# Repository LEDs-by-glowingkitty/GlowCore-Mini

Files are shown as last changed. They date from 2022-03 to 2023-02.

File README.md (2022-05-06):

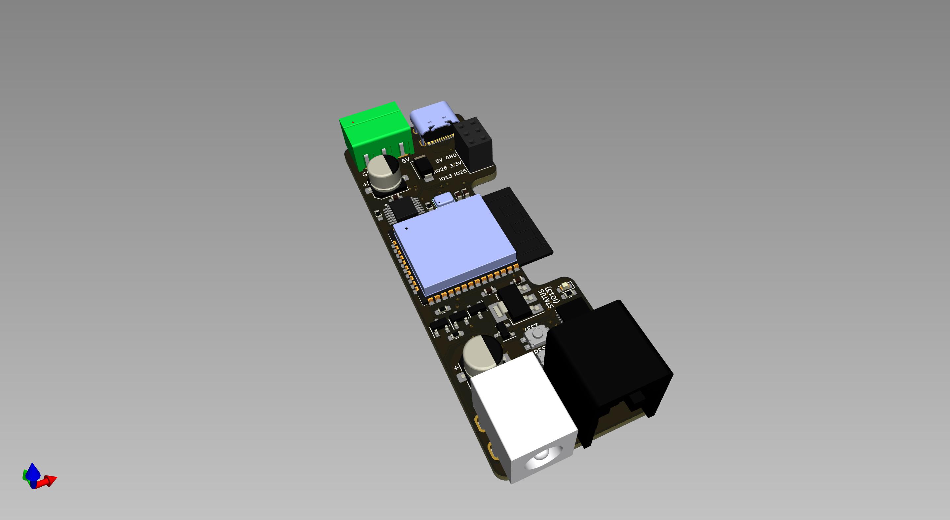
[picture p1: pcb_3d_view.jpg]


# GlowCoreMini

## Warning:

This project is currently under active development and has not been fully tested yet. If you decide to build or clone the project, be aware the project might not work yet as expected. Use at your own risk.

## What is this project?

A small PCB for controlling one LED strip. Program the integrated ESP32, and power everything via USB-C or DC power.

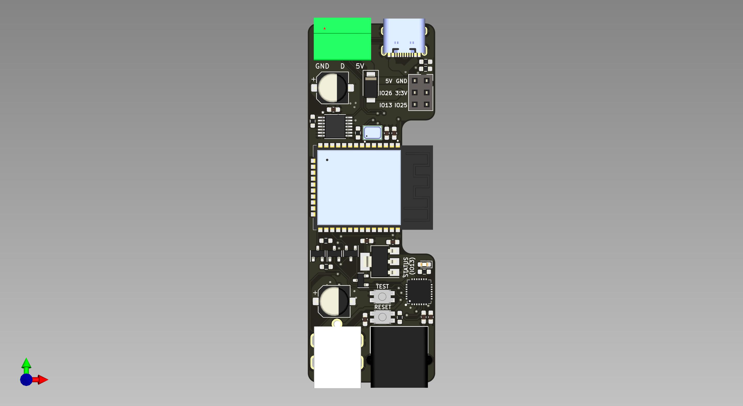
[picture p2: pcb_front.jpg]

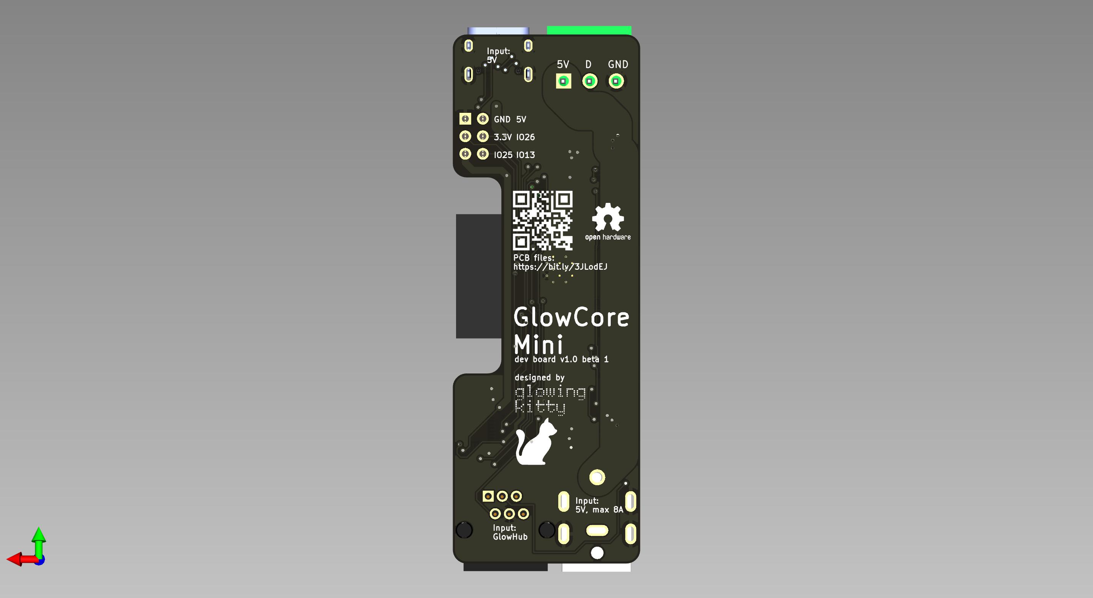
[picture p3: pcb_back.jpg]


## Links

- [Schematic](https://github.com/glowingkitty/GlowCoreMini/blob/main/GlowCoreMini.pdf)
- [Interactive BOM](https://htmlpreview.github.io/?https://github.com/glowingkitty/GlowCoreMini/blob/main/bom/ibom.html)
- [PCB stencils](https://github.com/glowingkitty/GlowCoreMini/blob/main/PCB%20stencils)

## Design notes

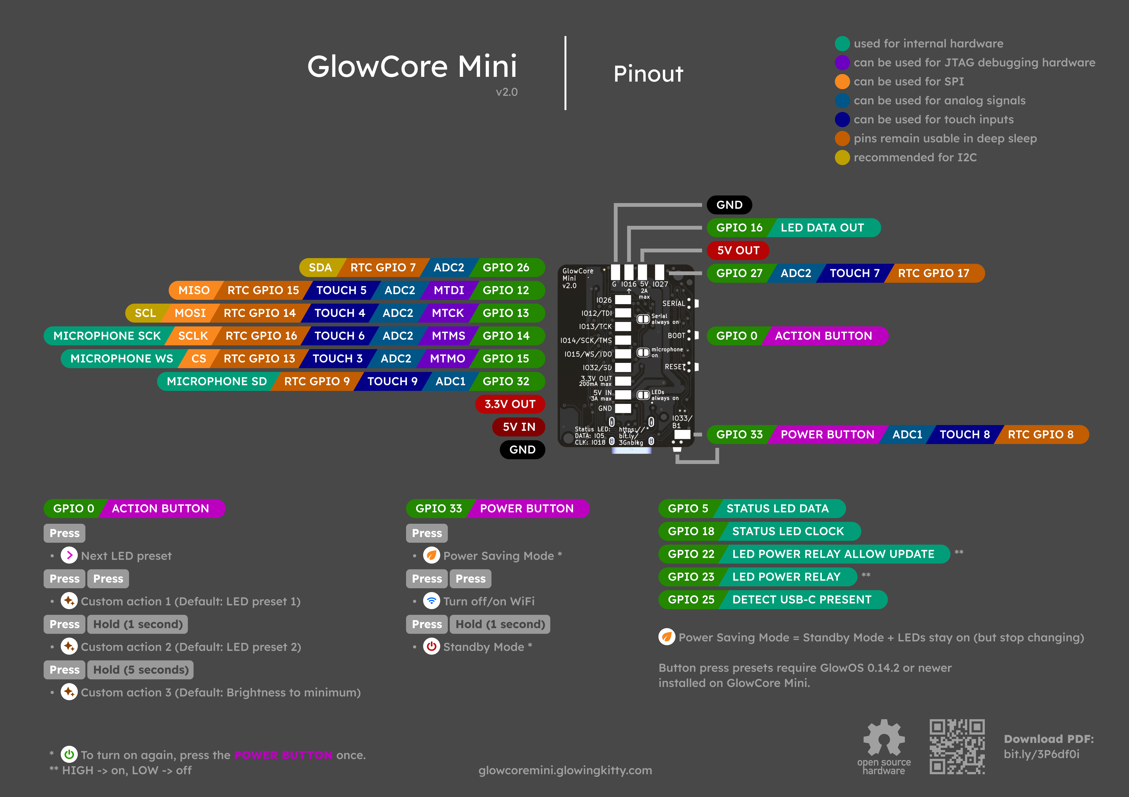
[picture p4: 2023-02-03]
documents/pinout GlowCore Mini v2.0.jpg

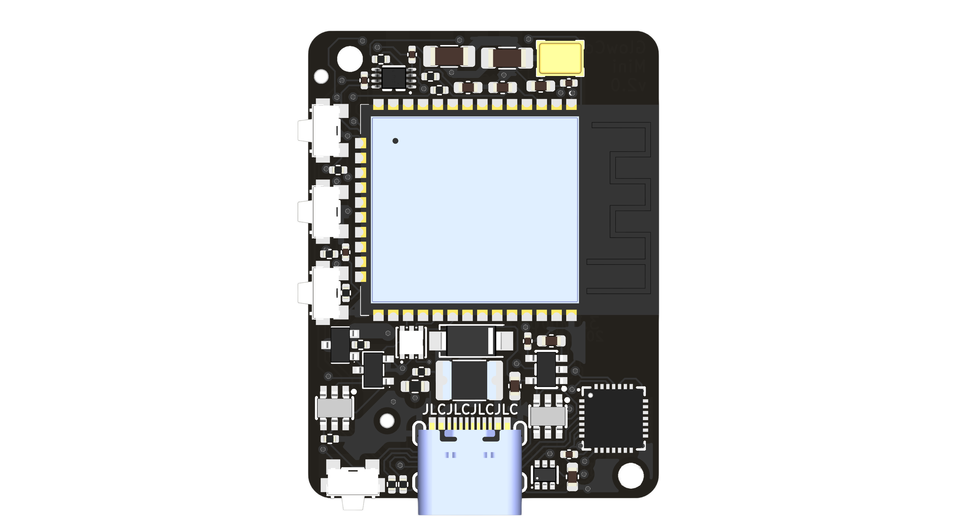
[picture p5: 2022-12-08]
images/GlowCoreMini PCB cutout.png

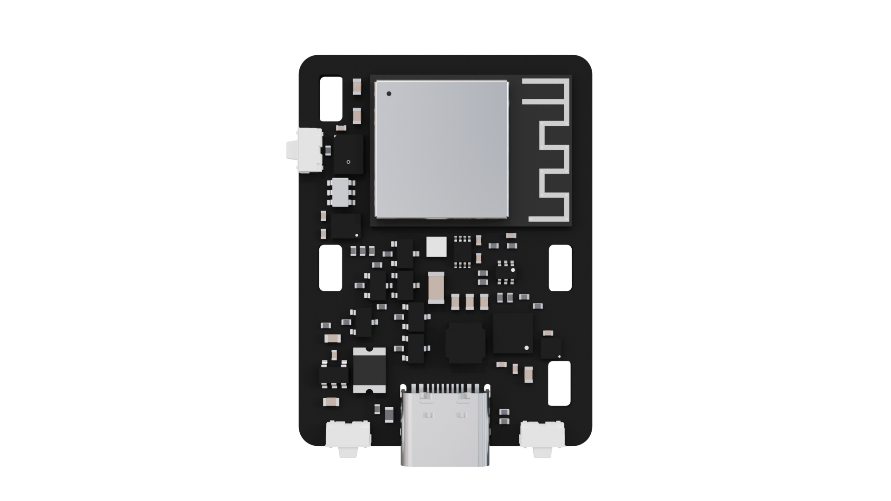
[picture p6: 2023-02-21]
renders/front.png

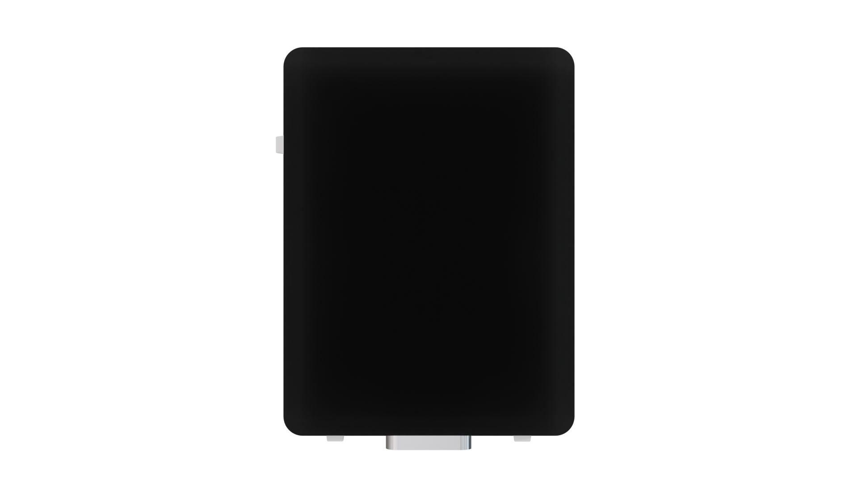
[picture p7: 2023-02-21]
renders/frontwithcase.png

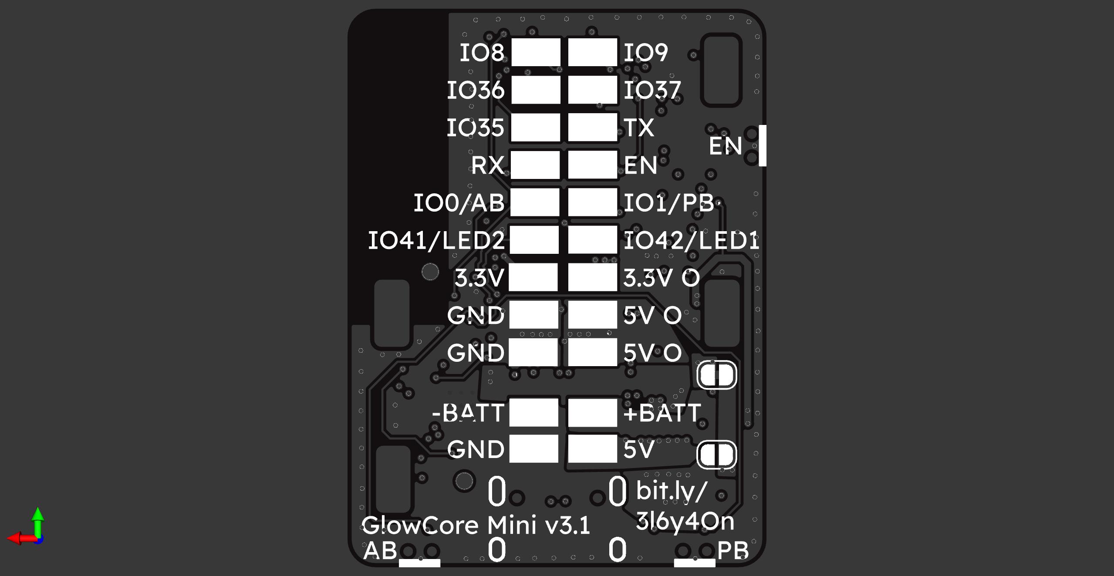
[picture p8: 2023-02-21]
3D files/Blender files/textures/pcb_back.jpg

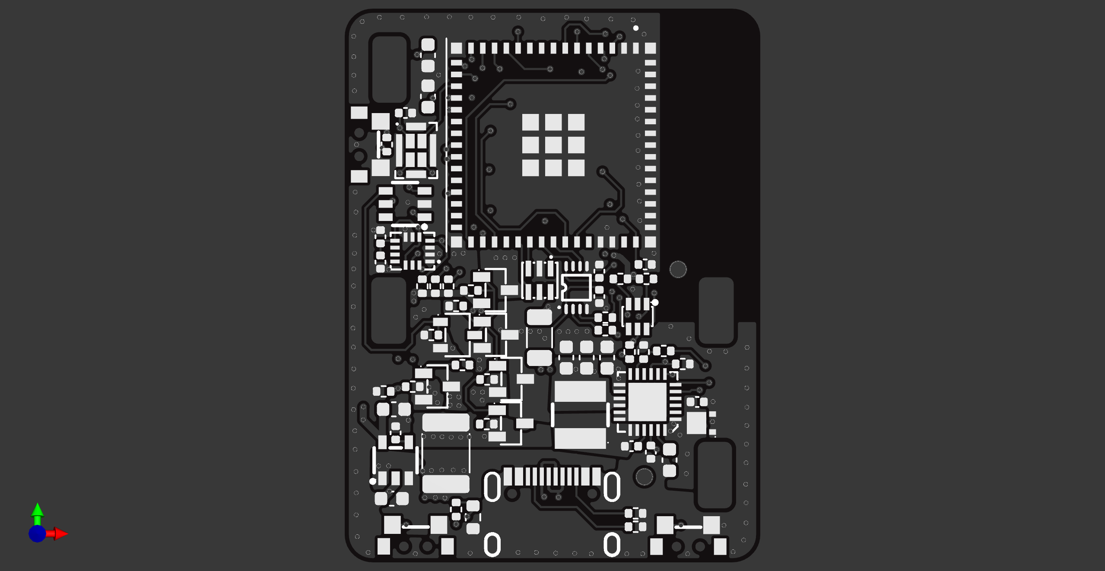
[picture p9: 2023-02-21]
3D files/Blender files/textures/pcb_front.png

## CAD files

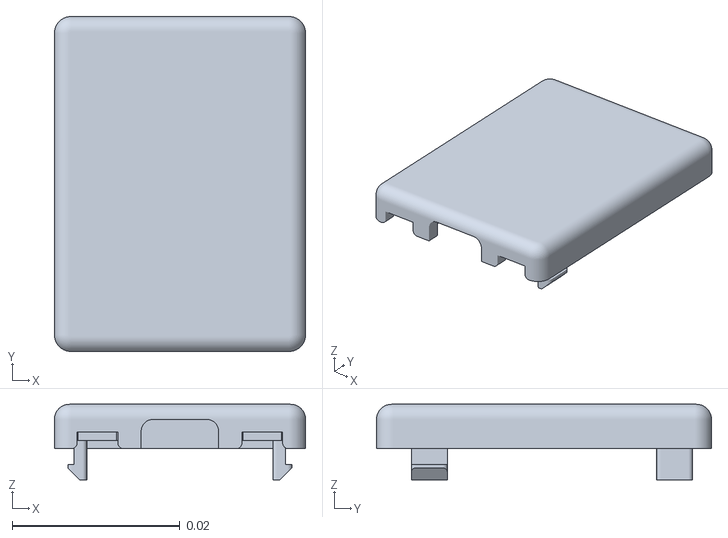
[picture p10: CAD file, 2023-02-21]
3D files/Blender files/case.obj
0.03 x 0.04 x 0.00902

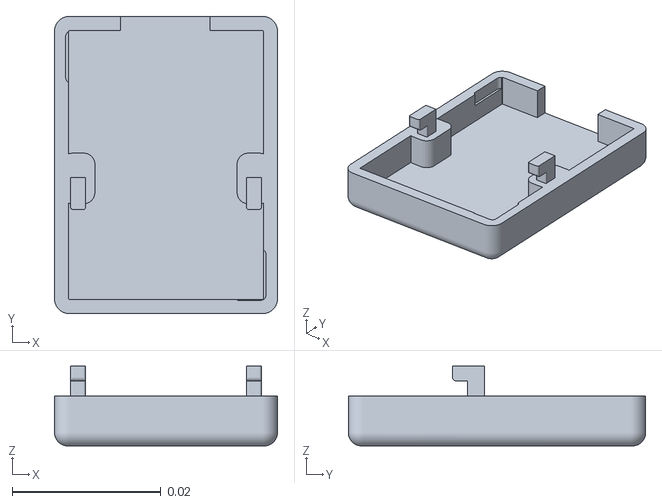
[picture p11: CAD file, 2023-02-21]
3D files/Blender files/back case.obj
0.03 x 0.04 x 0.0108

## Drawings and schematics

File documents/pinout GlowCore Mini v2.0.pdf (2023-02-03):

# GlowCore Mini

# Pinout

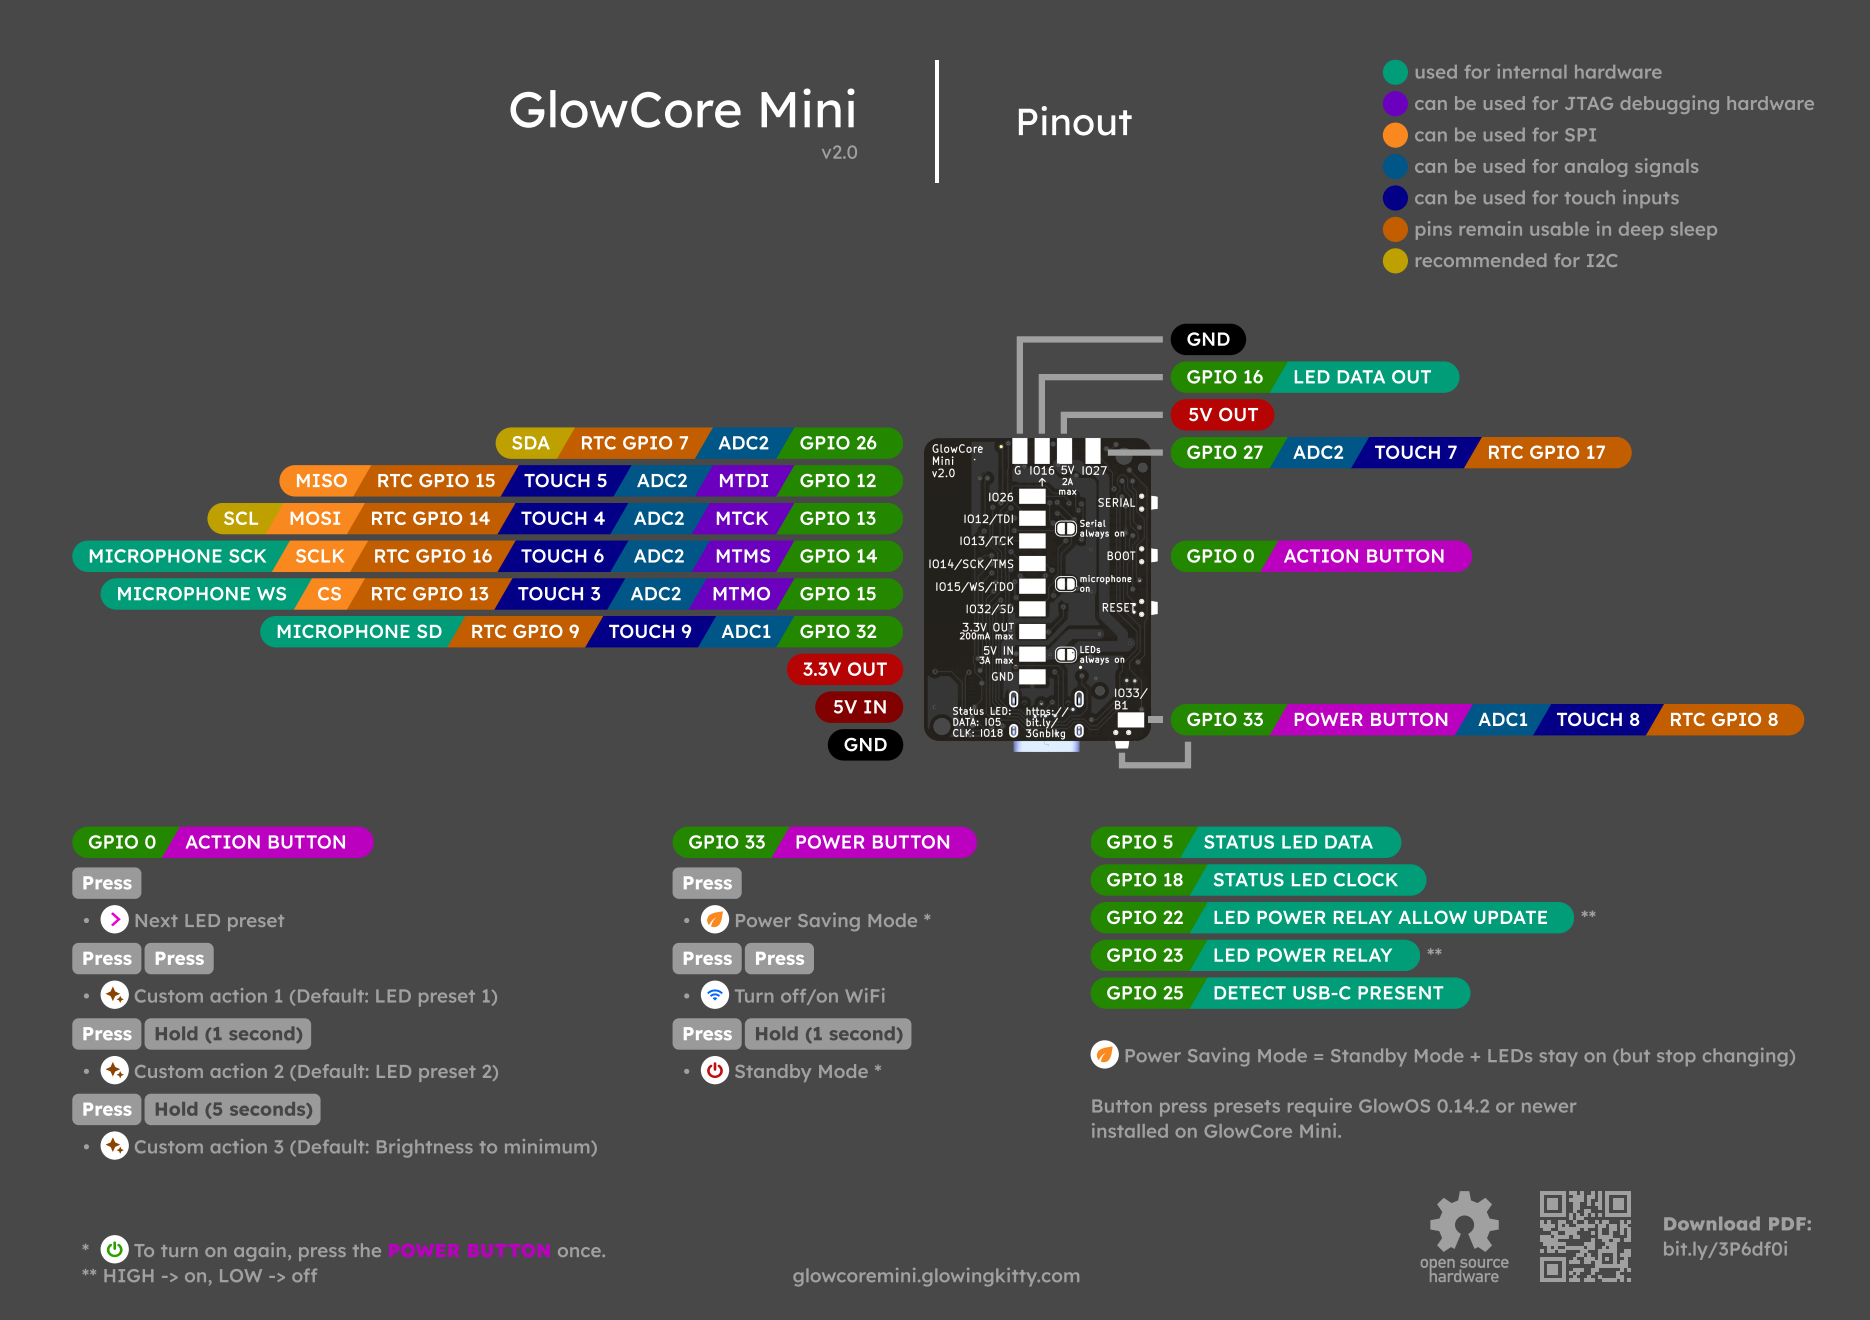
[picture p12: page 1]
recommended for I2C; SDA; RTC GPIO 7; ADC2; GPIO 26; MISO; RTC GPIO 15; TOUCH 5; MTDI; GPIO 12; SCL; MOSI; RTC GPIO 14; TOUCH 4; MTCK; GPIO 13; MICROPHONE SCK; SCLK; RTC GPIO 16; TOUCH 6; MTMS; GPIO 14; MICROPHONE WS; RTC GPIO 13; TOUCH 3; MTMO; GPIO 15; MICROPHONE SD; RTC GPIO 9; TOUCH 9; ADC1; GPIO 32; 3.3V OUT; GND; GPIO 16; LED DATA OUT; 5V OUT; GPIO 27; TOUCH 7; RTC GPIO 17; GPIO 33; POWER BUTTON; TOUCH 8; RTC GPIO 8; GPIO 0; ACTION BUTTON; GPIO 5; STATUS LED DATA; GPIO 18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

used for internal hardware

can be used for JTAG debugging hardware

can be used for SPI

can be used for analog signals

can be used for touch inputs

pins remain usable in deep sleep

Power Saving Mode = Standby Mode + LEDs stay on (but stop changing)

Press & hold 5 sec

Button press presets require GlowOS 0.14.2 or newer

installed on GlowCore Mini.

** HIGH -> on, LOW -> off

glowcoremini.glowingkitty.com

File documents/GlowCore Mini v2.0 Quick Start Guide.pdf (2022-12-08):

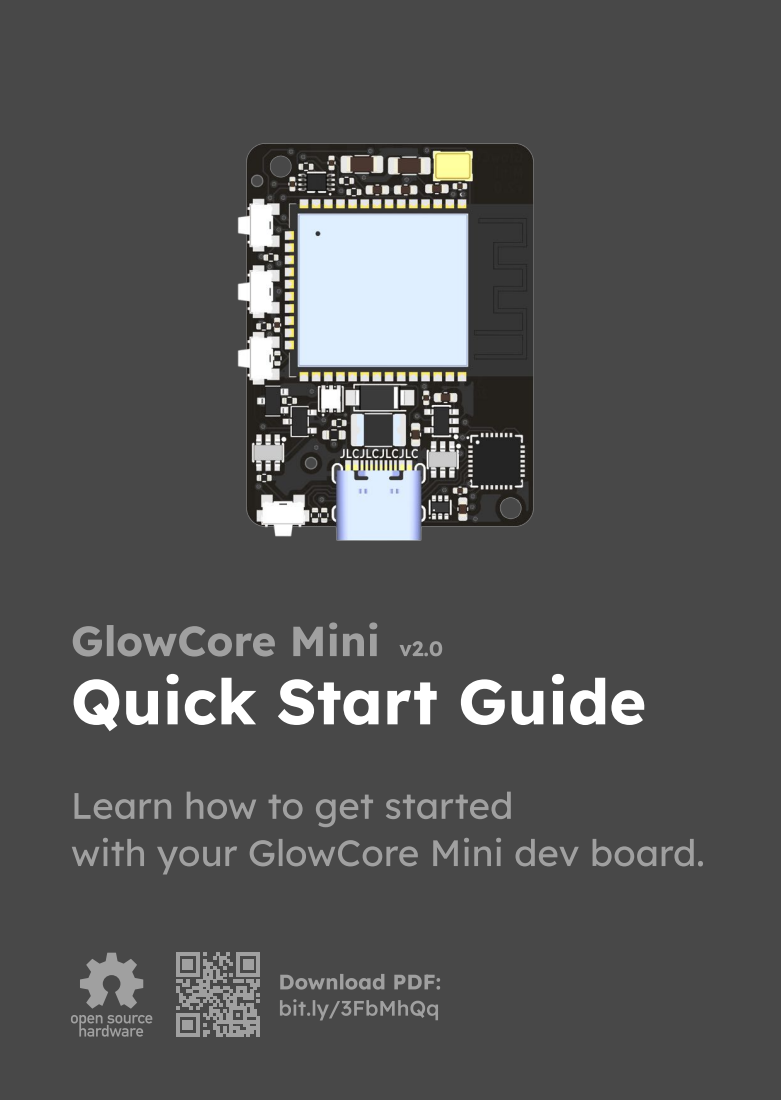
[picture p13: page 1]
Download PDF: bit.ly/3FbMhQq

GlowCore Mini v2.0
Quick Start Guide

Learn how to get started
with your GlowCore Mini dev board.

## bit.ly/3P6df0i

# Step 1:

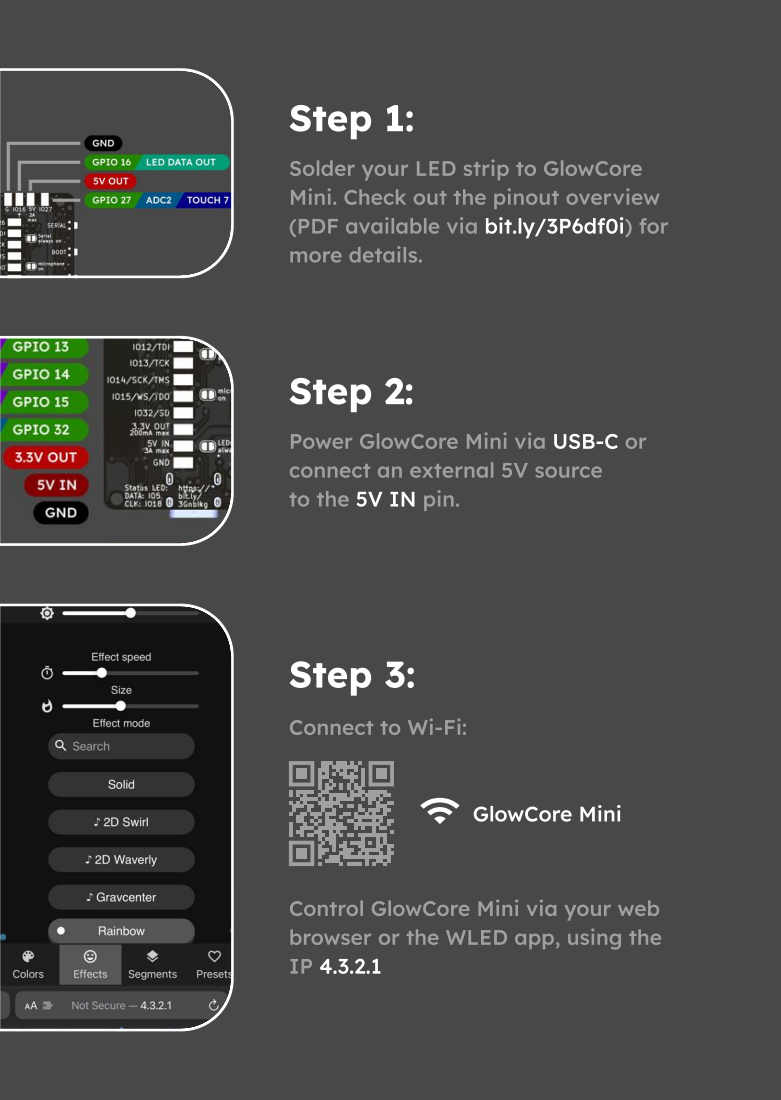
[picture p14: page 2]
(PDF available via; ) for; more details.; GlowCore Mini; Power GlowCore Mini via; to the; pin.; USB-C; Step 2:; Step 3:

Solder your LED strip to GlowCore

Mini. Check out the pinout overview

connect an external 5V source

Connect to Wi-Fi:

Control GlowCore Mini via your web

browser or the WLED app, using the

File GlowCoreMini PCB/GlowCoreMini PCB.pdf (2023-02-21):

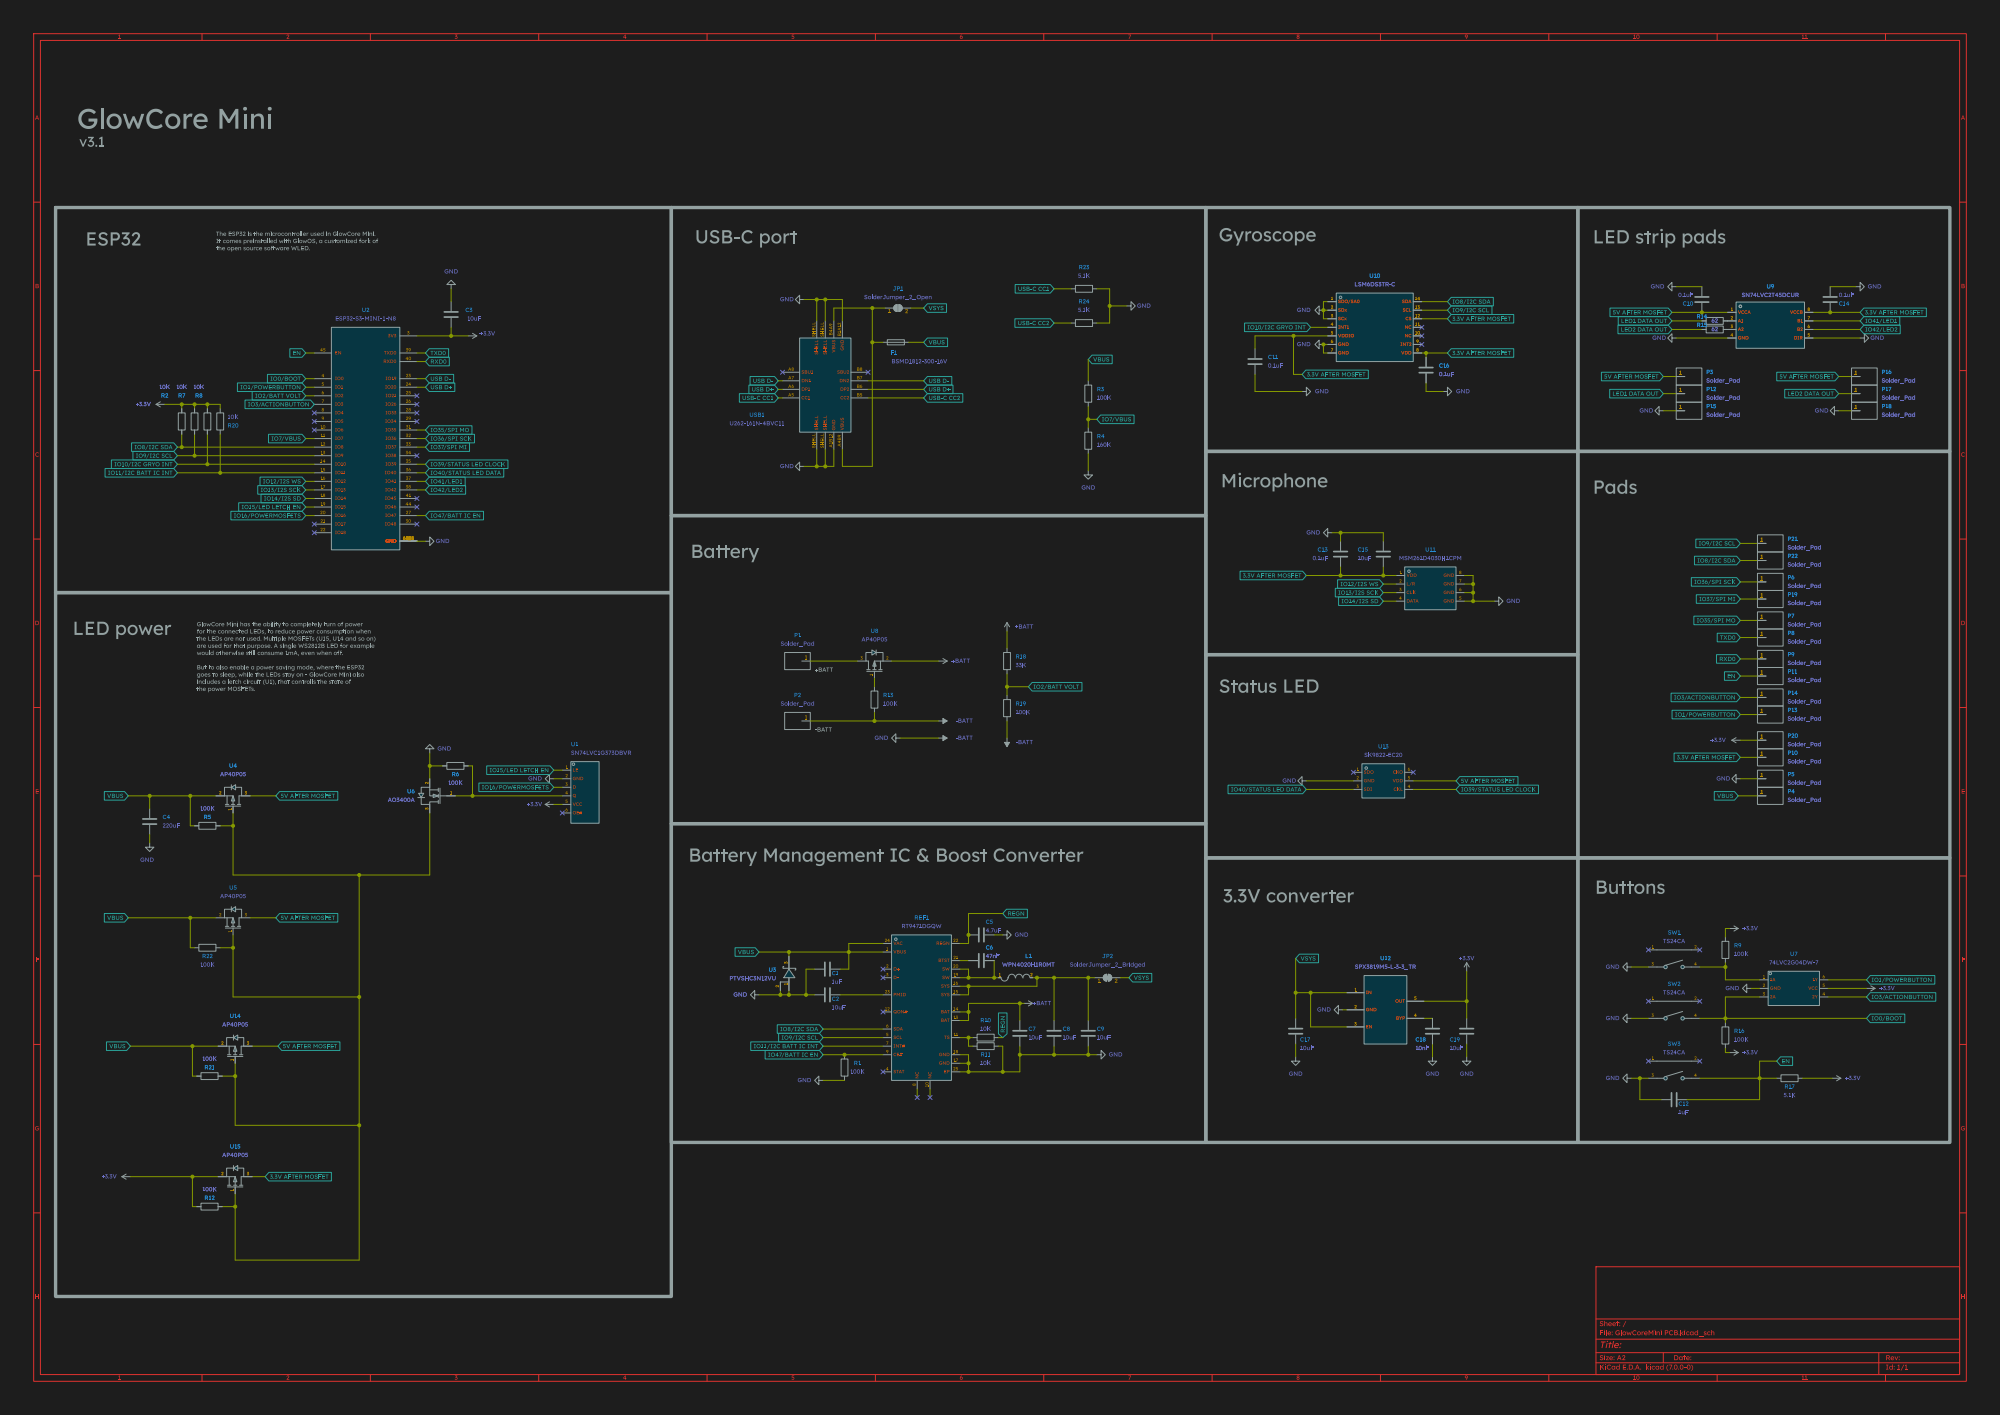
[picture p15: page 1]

It comes preinstalled with GlowOS, a customized fork of

VBUS USB D- USB-C CC1 USB D+ USB D-

IO40/STATUS LED DATA USB D+

the power MOSFETs. LED power

GlowCore Mini has the ability to completely turn of power
for the connected LEDs, to reduce power consumption when
the LEDs are not used. Multiple MOSFETs(U15, U14 and so on) are used for that purpose. A single WS2812B LED for example would otherwise still consume 1mA, even when off. But to also enable a power saving mode, where the ESP32

goes to sleep, while the LEDs stay on - GlowCore Mini also
includes a letch circuit (U1), that controlls the state of

Id: 1/1 Title: File: GlowCoreMini PCB.kicad_sch Sheet: /

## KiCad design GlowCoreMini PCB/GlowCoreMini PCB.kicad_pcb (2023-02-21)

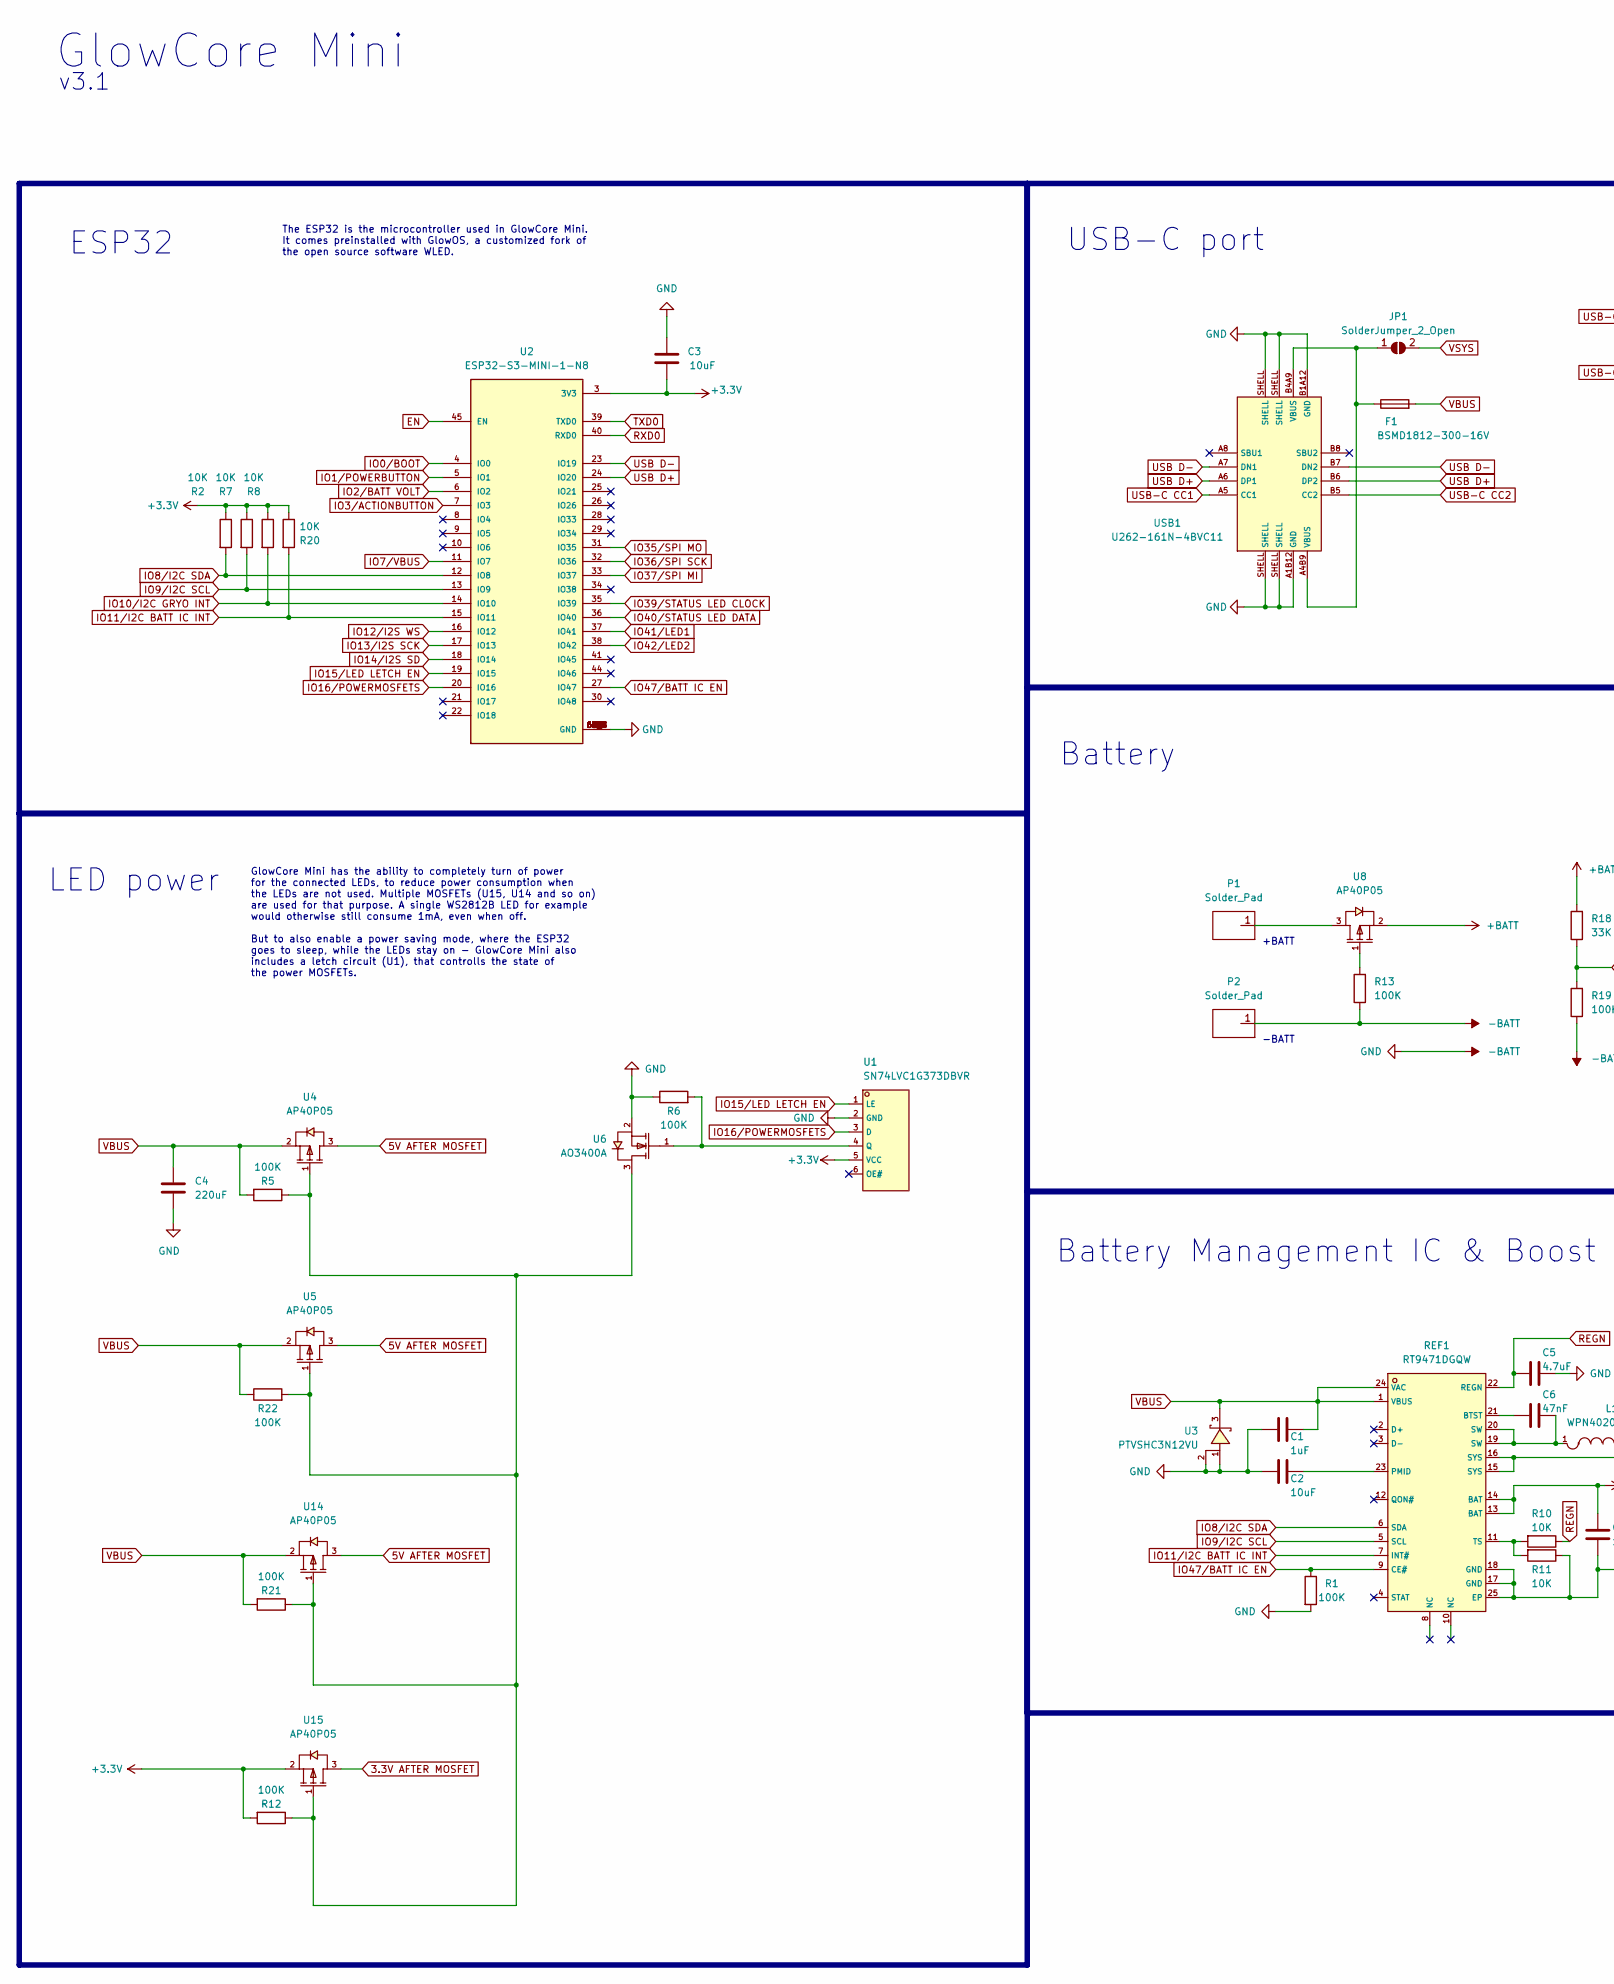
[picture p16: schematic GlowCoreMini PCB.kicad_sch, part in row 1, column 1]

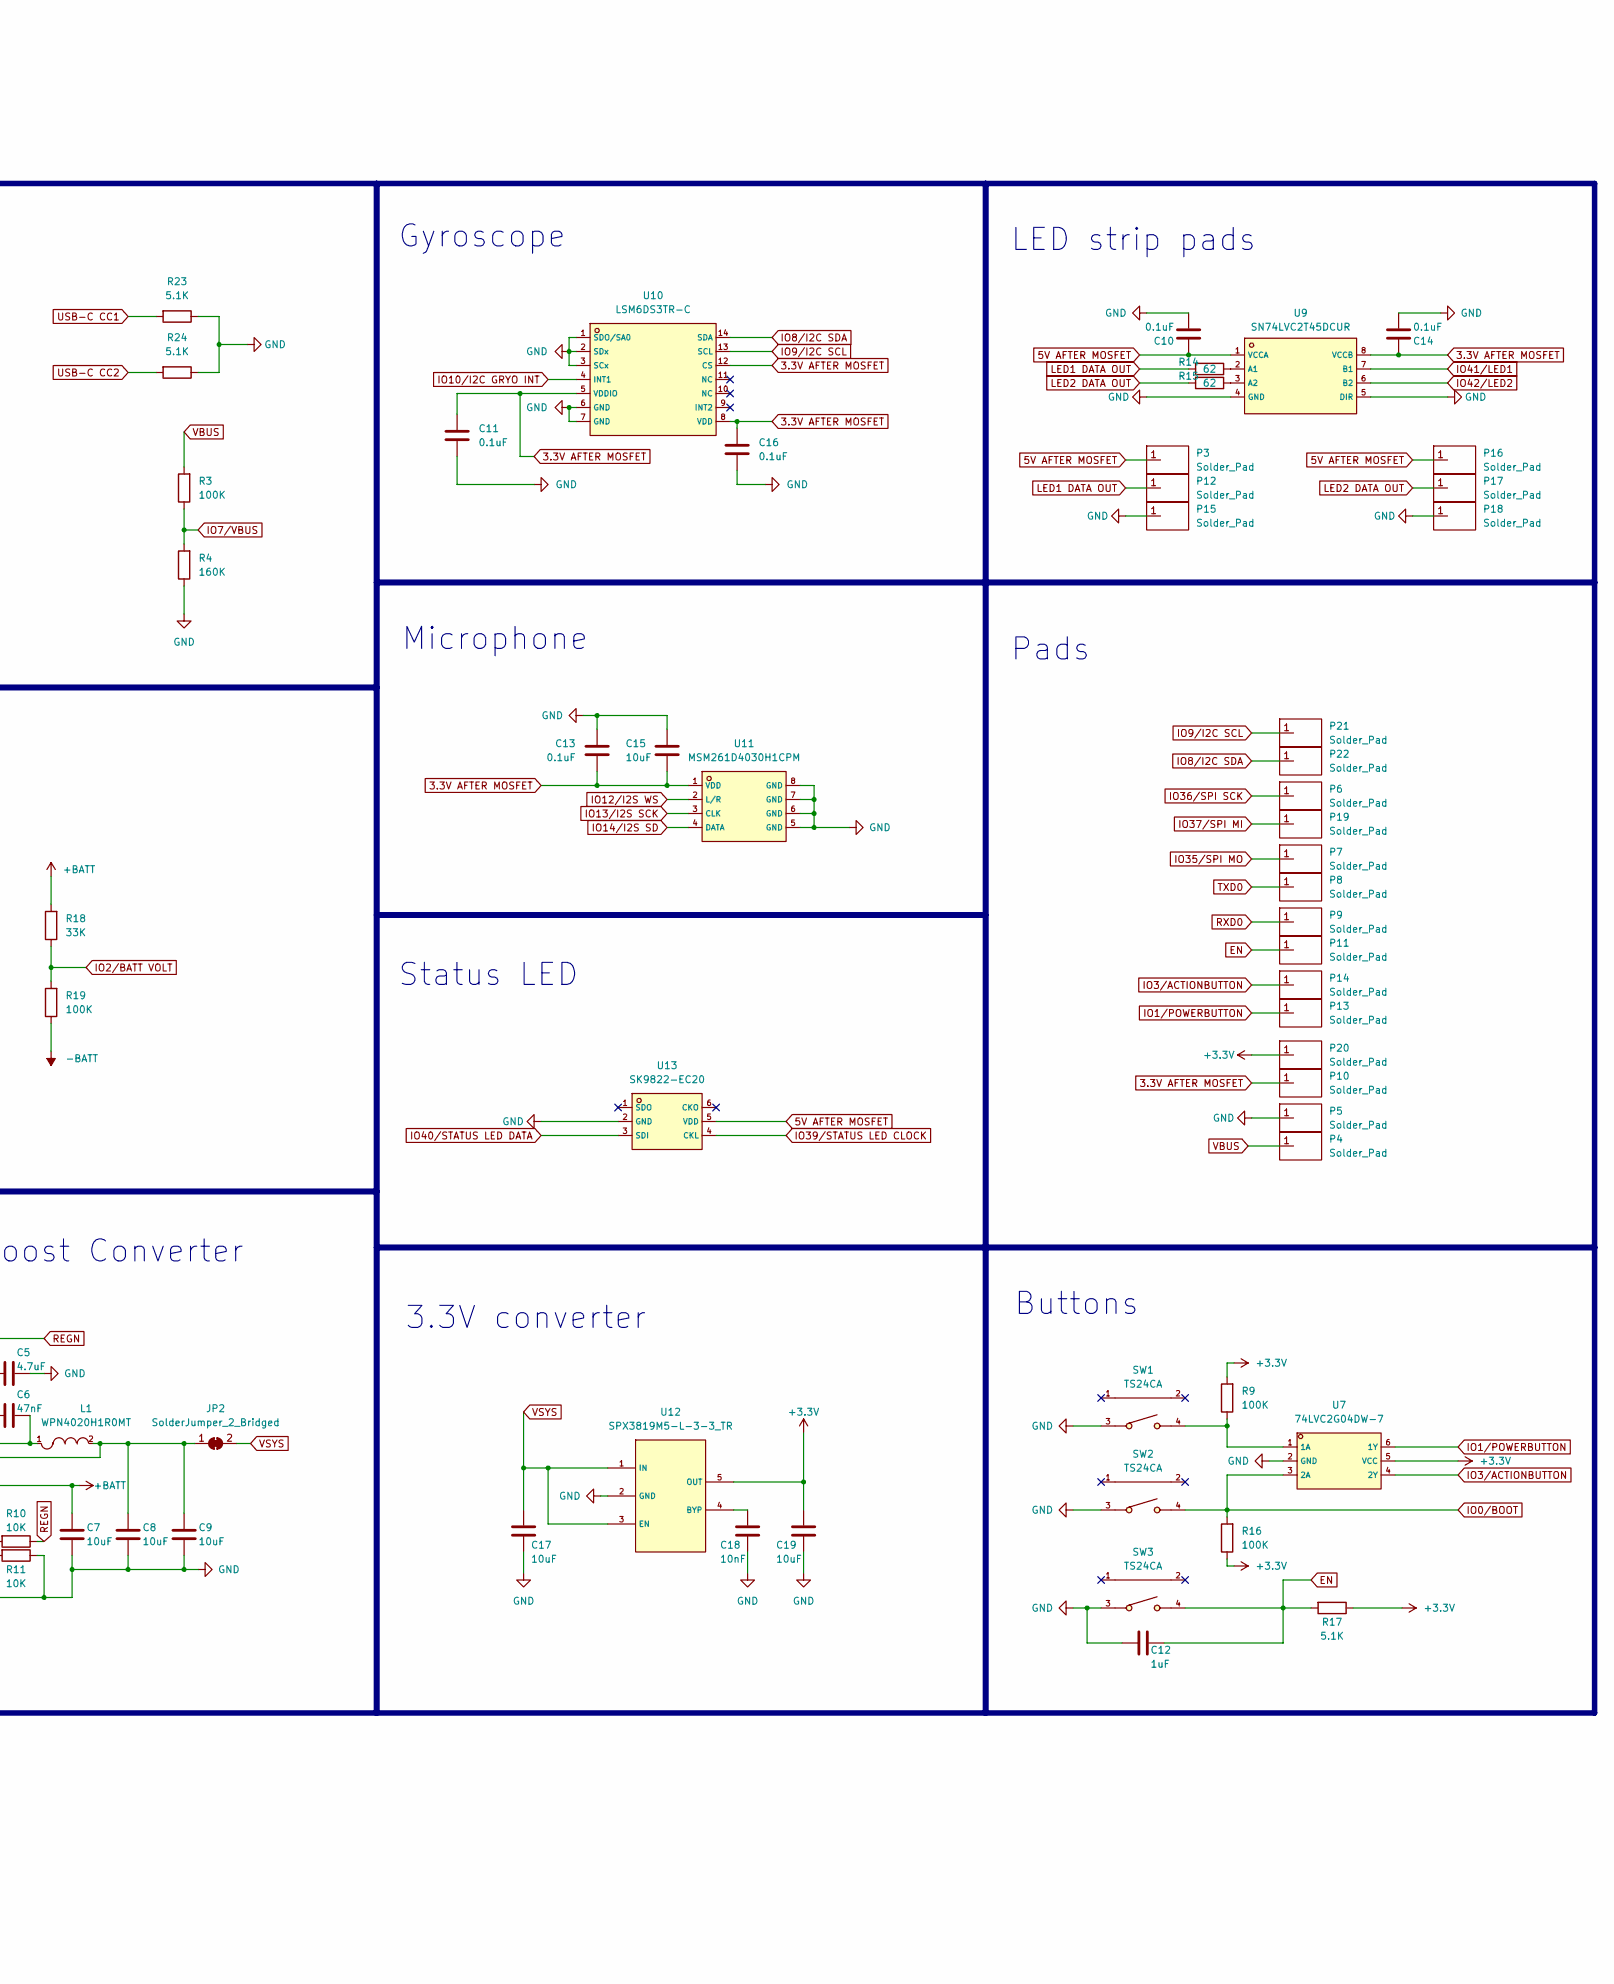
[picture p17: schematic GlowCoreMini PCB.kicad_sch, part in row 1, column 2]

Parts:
C1, C12: 1uF; C_0402_1005Metric; LCSC # C52923
C2, C3, C7, C8, C9, C15, C17, C19: 10uF; C_0603_1608Metric; LCSC # C96446
C4: 220uF; C_1206_3216Metric; LCSC # C412252
C5: 4.7uF; C_0402_1005Metric; LCSC # C23733
C6: 47nF; C_0402_1005Metric; LCSC # C505502
C10, C11, C13, C14, C16: 0.1uF; C_0402_1005Metric; LCSC # C1525
C18: 10nF; C_0402_1005Metric; LCSC # C15195
F1: BSMD1812-300-16V; Fuse_1812_4532Metric_Pad1.30x3.40mm_HandSolder; LCSC # C883162
JP1: SolderJumper_2_Open; SolderJumper-2_P1.3mm_Open_RoundedPad1.0x1.5mm
JP2: SolderJumper_2_Bridged; SolderJumper-2_P1.3mm_Bridged_RoundedPad1.0x1.5mm
L1: WPN4020H1R0MT; IND-SMD_L4.0-W4.0_SLW40XX; LCSC C98359
P1, P2, P3, P4, P5, P6, P7, P8, P9, P10, P11, P12, P13, P14, P15, P16, P17, P18, P19, P20, P21, P22: Solder_Pad; Solder pad
R1, R3, R5, R6, R9, R12, R13, R16, R19, R21, R22: 100K; R_0402_1005Metric; LCSC # C25741
R2, R7, R8, R10, R11, R20: 10K; R_0402_1005Metric; LCSC # C25744
R4: 160K; R_0603_1608Metric; LCSC # C22813
R14, R15: 62; R_0402_1005Metric; LCSC # C4962
R17, R23, R24: 5.1K; R_0402_1005Metric; LCSC # C25905
R18: 33K; R_0402_1005Metric; LCSC # C25779
REF1: RT9471DGQW; RT9471_vias_in_pad; LCSC C2839437
SW1, SW2, SW3: TS24CA; SW-SMD_TS24CA; LCSC C393942
U1: SN74LVC1G373DBVR; SOT-23-6_L2.9-W1.6-P0.95-LS2.8-BR; LCSC C128413
U2: ESP32-S3-MINI-1-N8; LCSC# C2913206
U3: PTVSHC3N12VU; DFN-3_L2.0-W2.0-P1.30-BR; LCSC C110755
U4, U5, U8, U14, U15: AP40P05; SOT-23-3_L2.9-W1.3-P1.90-LS2.4-BR; LCSC # C2886385
U6: AO3400A; SOT-23-3_L2.9-W1.6-P1.90-LS2.8-BR; LCSC # C20917
U7: 74LVC2G04DW-7; SOT-363_L2.0-W1.3-P0.65-LS2.1-BR; LCSC C69053
U9: SN74LVC2T45DCUR; VSSOP-8_L2.4-W2.1-P0.50-LS3.2-BR; LCSC # C15741
U10: LSM6DS3TR-C; LGA-14_L3.0-W2.5-P0.50-TL; LCSC C967633
U11: MSM261D4030H1CPM; MIC-SMD_8P-L4.0-W3.0_ZTS6231; LCSC C966942
U12: SPX3819M5-L-3-3_TR; SOT-23-5_L3.0-W1.7-P0.95-LS2.8-BR; LCSC # C9055
U13: SK9822-EC20; LED-SMD_6P-L2.0-W2.0-P0.80-TL; LCSC C2909059
USB1: U262-161N-4BVC11; USB-3.1-SMD_U262-161N-4BVC11; LCSC # C319148

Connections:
3.3V AFTER MOSFET: C11.1, C13.2, C14.1, C15.2, C16.1, P10.1, U9.8 (VCCB), U10.5 (VDDIO), U10.8 (VDD), U10.12 (CS), U11.1 (VDD), U15.3 (D)
5V AFTER MOSFET: C10.1, P3.1, P16.1, U4.3 (D), U5.3 (D), U9.1 (VCCA), U13.5 (VDD), U14.3 (D)
+3V3: C3.2, C19.2, P20.1, R2.1, R7.1, R8.1, R9.2, R12.2, R16.1, R17.1, R20.1, U1.5 (VCC), U2.3 (3V3), U7.5 (VCC), U12.5 (OUT), U15.2 (S)
+BATT: C7.2, R18.2, REF1.13 (BAT), REF1.14 (BAT), U8.2 (S)
-BATT: C1.1, C2.1, C3.1, C4.2, C5.2, C7.1, C8.1, C9.1, C10.2, C11.2, C12.1, C13.1, C14.2, C15.1, C16.2, C17.1, C18.1, C19.1, P2.1, P5.1, P15.1, P18.1, R1.2, R4.1, R6.1, R11.1, R13.1, R19.1, R23.1, R24.1, REF1.17 (GND), REF1.18 (GND), REF1.25 (EP), SW1.3, SW2.3, SW3.3, U1.2 (GND), U2.1 (GND), U2.2 (GND), U2.42 (GND), U2.43 (GND), U2.46 (GND), U2.47 (GND), U2.48 (GND), U2.49 (GND), U2.50 (GND), U2.51 (GND), U2.52 (GND), U2.53 (GND), U2.54 (GND), U2.55 (GND), U2.56 (GND), U2.57 (GND), U2.58 (GND), U2.59 (GND), U2.60 (GND), U2.61 (GND), U2.61_1 (GND), U2.61_2 (GND), U2.61_3 (GND), U2.61_4 (GND), U2.61_5 (GND), U2.61_6 (GND), U2.61_7 (GND), U2.61_8 (GND), U2.62 (GND), U2.63 (GND), U2.64 (GND), U2.65 (GND), U3.1 (A), U3.2 (1), U6.2 (S), U7.2 (GND), U9.4 (GND), U9.5 (DIR), U10.1 (SDO/SA0), U10.2 (SDx), U10.3 (SCx), U10.6 (GND), U10.7 (GND), U11.5 (GND), U11.6 (GND), U11.7 (GND), U11.8 (GND), U12.2 (GND), U13.2 (GND), USB1.A1B12 (GND), USB1.B1A12 (GND), USB1.SHELL
EN: C12.2, P11.1, R17.2, SW3.4, U2.45 (EN)
IO0/BOOT: R16.2, SW2.4, U2.4 (IO0), U7.3 (2A)
IO1/POWERBUTTON: P13.1, U2.5 (IO1), U7.6 (1Y)
IO2/BATT VOLT: R18.1, R19.2, U2.6 (IO2)
IO3/ACTIONBUTTON: P14.1, U2.7 (IO3), U7.4 (2Y)
IO7/VBUS: R3.1, R4.2, U2.11 (IO7)
IO8/I2C SDA: P22.1, R2.2, REF1.6 (SDA), U2.12 (IO8), U10.14 (SDA)
IO9/I2C SCL: P21.1, R7.2, REF1.5 (SCL), U2.13 (IO9), U10.13 (SCL)
IO10/I2C GRYO INT: R8.2, U2.14 (IO10), U10.4 (INT1)
IO11/I2C BATT IC INT: R20.2, REF1.7 (INT#), U2.15 (IO11)
IO12/I2S WS: U2.16 (IO12), U11.2 (L/R)
IO13/I2S SCK: U2.17 (IO13), U11.3 (CLK)
IO14/I2S SD: U2.18 (IO14), U11.4 (DATA)
IO15/LED LETCH EN: U1.1 (LE), U2.19 (IO15)
IO16/POWERMOSFETS: U1.3 (D), U2.20 (IO16)
IO35/SPI MO: P7.1, U2.31 (IO35)
IO36/SPI SCK: P6.1, U2.32 (IO36)
IO37/SPI MI: P19.1, U2.33 (IO37)
IO39/STATUS LED CLOCK: U2.35 (IO39), U13.4 (CKL)
IO40/STATUS LED DATA: U2.36 (IO40), U13.3 (SDI)
IO41/LED1: U2.37 (IO41), U9.7 (B1)
IO42/LED2: U2.38 (IO42), U9.6 (B2)
IO47/BATT IC EN: R1.1, REF1.9 (CE#), U2.27 (IO47)
LED1 DATA OUT: P12.1, R14.2
LED2 DATA OUT: P17.1, R15.2
unnamed: C6.2, L1.1, REF1.19 (SW), REF1.20 (SW)
unnamed: F1.1, JP1.1 (A), USB1.A4B9 (VBUS), USB1.B4A9 (VBUS)
unnamed: C8.2, C9.2, JP2.1 (A), L1.2, REF1.15 (SYS), REF1.16 (SYS)
unnamed: C6.1, REF1.21 (BTST)
unnamed: C2.2, REF1.23 (PMID)
unnamed: R10.2, R11.2, REF1.11 (TS)
unnamed: R6.2, U1.4 (Q), U6.1 (G)
unnamed: R9.1, SW1.4, U7.1 (1A)
unnamed: P1.1, U8.3 (D)
unnamed: R13.2, U8.1 (G)
unnamed: R14.1, U9.2 (A1)
unnamed: R15.1, U9.3 (A2)
unnamed: C18.2, U12.4 (BYP)
unnamed: R5.1, R12.1, R21.1, R22.2, U4.1 (G), U5.1 (G), U6.3 (D), U14.1 (G), U15.1 (G)
REGN: C5.1, R10.1, REF1.22 (REGN)
RXD0: P9.1, U2.40 (RXD0)
TXD0: P8.1, U2.39 (TXD0)
USB D+: U2.24 (IO20), USB1.A6 (DP1), USB1.B6 (DP2)
USB D-: U2.23 (IO19), USB1.A7 (DN1), USB1.B7 (DN2)
USB-C CC1: R23.2, USB1.A5 (CC1)
USB-C CC2: R24.2, USB1.B5 (CC2)
VBUS: C1.2, C4.1, F1.2, P4.1, R3.2, R5.2, R21.2, R22.1, REF1.1 (VBUS), REF1.24 (VAC), U3.3 (K), U4.2 (S), U5.2 (S), U14.2 (S)
VSYS: C17.2, JP1.2 (B), JP2.2 (B), U12.1 (IN), U12.3 (EN)

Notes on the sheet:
3.3V converter
Buttons
LED power
LED strip pads
GlowCore Mini
The ESP32 is the microcontroller used in GlowCore Mini. It comes preinstalled with GlowOS, a customized fork of the open source software WLED.
v3.1
-BATT
+BATT
Status LED
Battery Management IC & Boost Converter
Gyroscope
Pads
USB-C port
Microphone
Battery
ESP32
GlowCore Mini has the ability to completely turn of power for the connected LEDs, to reduce power consumption when the LEDs are not used. Multiple MOSFETs (U15, U14 and so on) are used for that purpose. A single WS2812B LED for example would otherwise still consume 1mA, even when off. But to also e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

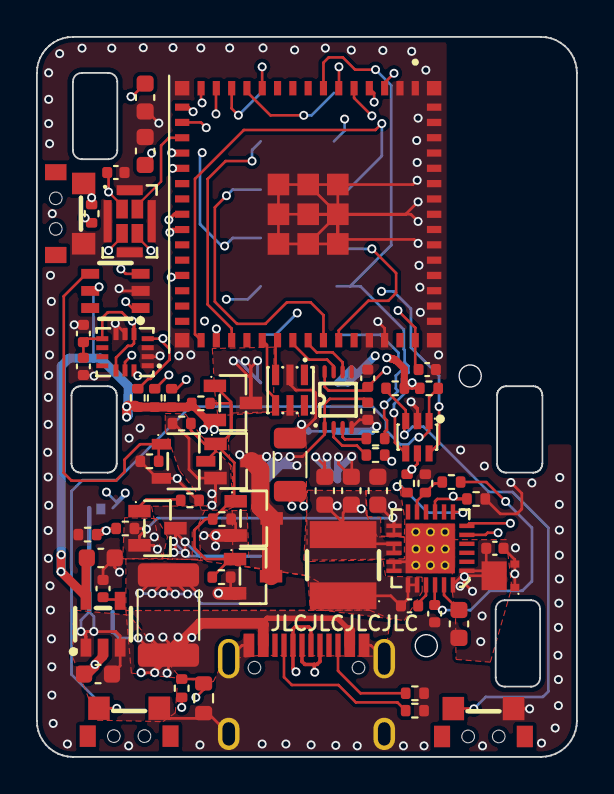
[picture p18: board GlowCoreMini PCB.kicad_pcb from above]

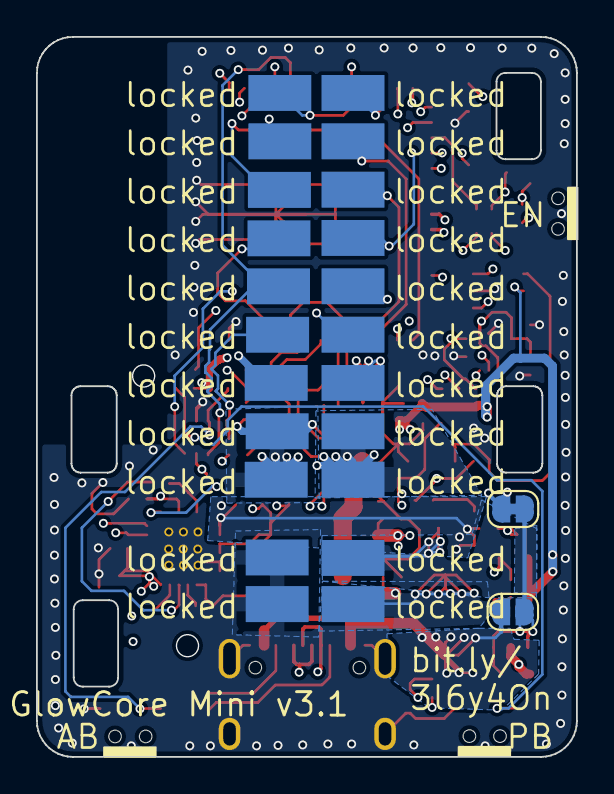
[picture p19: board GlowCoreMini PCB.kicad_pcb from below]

Board: 4 copper layers, 30.0 x 40.0 mm, 89 parts (24 on the bottom side), 53 nets.

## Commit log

2022-01-27 added first PCB design (still in development)
    [GlowCoreMini-B_Cu.gbr, GlowCoreMini-B_Mask.gbr, GlowCoreMini-B_Paste.gbr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]
2022-01-27 added updated design (in development)
    [GlowCoreMini-B_Cu.gbr, GlowCoreMini-B_Mask.gbr, GlowCoreMini-B_Paste.gbr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]
2022-01-27 added schematic and pcb pdf preview
2022-01-27 updated gitignore
    [BOM-GlowCoreMini.csv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]
2022-02-01 updated pcb design (still in dev)
    [BOM-GlowCoreMini.csv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]
2022-02-03 last fixes to prototype v1
    [BOM-GlowCoreMini.csv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]
2022-02-03 added images to readme
    [GlowCoreMini-CuBottom.gbr, GlowCoreMini-CuTop.gbr, GlowCoreMini-EdgeCuts.gbr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]
2022-02-21 update design
    [GlowCoreMini-CuBottom.gbr, GlowCoreMini-CuTop.gbr, GlowCoreMini-EdgeCuts.gbr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]
2022-02-25 work on updated pcb design
    [GlowCoreMini-CuBottom.gbr, GlowCoreMini-CuTop.gbr, GlowCoreMini-EdgeCuts.gbr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]
2022-03-03 access ibom via github pages
    [GlowCoreMini.kicad_pcb]
2022-03-13 added GlowCore Mini dev board v1.0 beta 1
    [GlowCoreMini-CuBottom.gbr, GlowCoreMini-CuTop.gbr, GlowCoreMini-EdgeCuts.gbr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]
2022-03-14 update images to latest pcb design
2022-03-14 add link to interactive bom
2022-03-14 added schematic link
2022-03-14 added 3d printable stencil
    [stencil.stl]
2022-03-25 added PCB stencils
    [GlowCoreMini.kicad_pcb, stencil.stl]
2022-05-06 add warning info
    [GlowCoreMini.kicad_pcb, GlowCoreMini.kicad_sch]
2022-08-24 started redesign
    [GlowCoreMini-CuBottom.gbr, GlowCoreMini-CuTop.gbr, GlowCoreMini-EdgeCuts.gbr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]
2022-11-16 redesigned GlowCore Mini
    [GlowCoreMini PCB-CuBottom.gbr, GlowCoreMini PCB-CuTop.gbr, GlowCoreMini PCB-EdgeCuts.gbr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]
2022-11-17 fixed via in ground pad
    [GlowCoreMini PCB-CuBottom.gbr, GlowCoreMini PCB-CuTop.gbr, GlowCoreMini PCB-EdgeCuts.gbr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]
2022-11-18 added status led
    [GlowCoreMini PCB-CuBottom.gbr, GlowCoreMini PCB-CuTop.gbr, GlowCoreMini PCB-EdgeCuts.gbr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]
2022-12-03 added pinout and case test mold
    [case b holder a.stl, case b holder b.stl, case b.stl]
2022-12-14 updated 3D printed case design
    [GlowCoreMini PCB.kicad_pcb, GlowCoreMini PCB.kicad_sch, case.stl]
2023-02-03 continued redesign of pcb
    [3_3_converter.kicad_sch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]
2023-02-05 split up schematic
    [3_3_converter.kicad_sch, GlowCoreMini PCB.kicad_pcb, GlowCoreMini_BattIC.kicad_sch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]
2023-02-10 updated pcb design
    [3_3_converter.kicad_sch, GlowCoreMini PCB.kicad_pcb, GlowCoreMini PCB.kicad_sch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]
2023-02-21 updated pcb
    [GlowCoreMini PCB.kicad_pcb, GlowCoreMini PCB.kicad_sch, back case.obj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]
